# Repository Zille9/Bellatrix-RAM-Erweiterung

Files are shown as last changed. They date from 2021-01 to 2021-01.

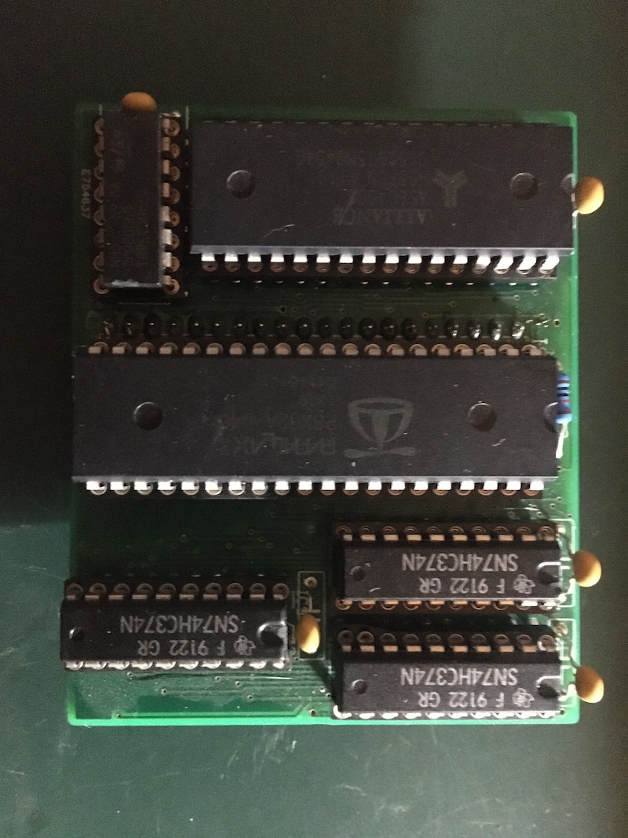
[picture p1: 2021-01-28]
RAM-Erw.JPG

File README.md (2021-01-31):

# Bellatrix-RAM-Erweiterung
Zusätzlicher E-RAM für Bellatrix für die Nutzung von CP/M, TRS80-Emulator, Spectrum-Emulator usw.

Diese Platine wird in den Bellatrixsockel des Hive-Computers gesteckt (Bellatrix selbst kommt auf die Erweiterungsplatine. 
Mit ihr ist es möglich die verschiedenen Emulatoren zu nutzen.
TRS80, ZX-Spectrum, Colour-Genie, Nascom.
Beim Hive-Max ist zusätzlich auch die CP/M-Emulation nutzbar.

HINWEIS: der Videoausgang des HIVE-Boards ist bei Verwendung der Ram-Erweiterung nicht mehr nutzbar. Es ist aber mit einem kleinen Umbau möglich, eine alternative Videofunktion zu realisieren (Pins müssen in den Programmen entsprechend angepasst werden Pin16-19). Siehe auch die Skizze TV.jpg

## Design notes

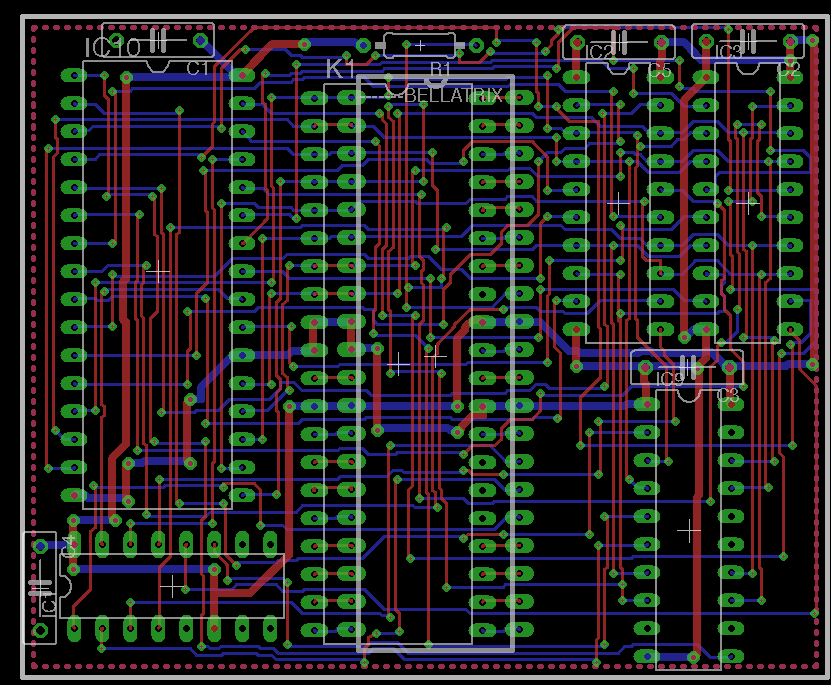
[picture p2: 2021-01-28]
Ram_upgrade_layout.png

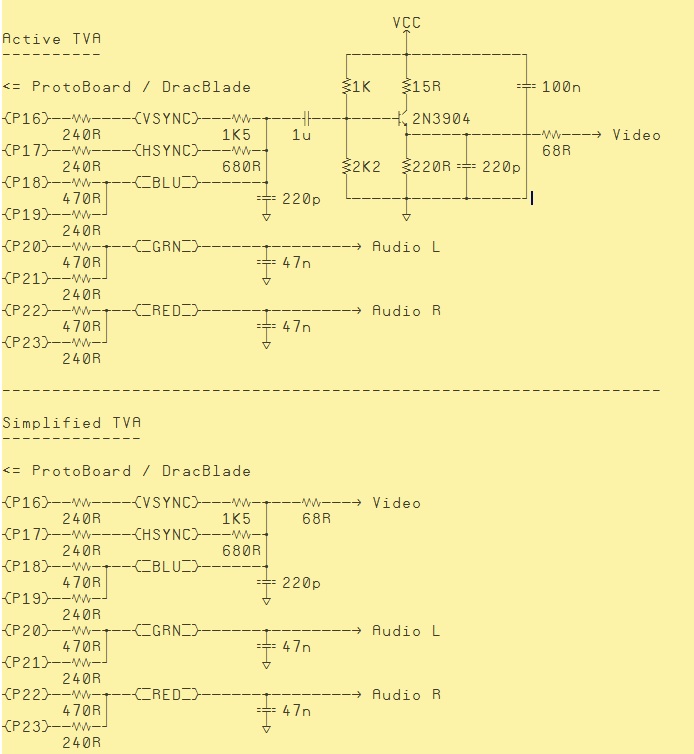
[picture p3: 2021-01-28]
TV.jpg

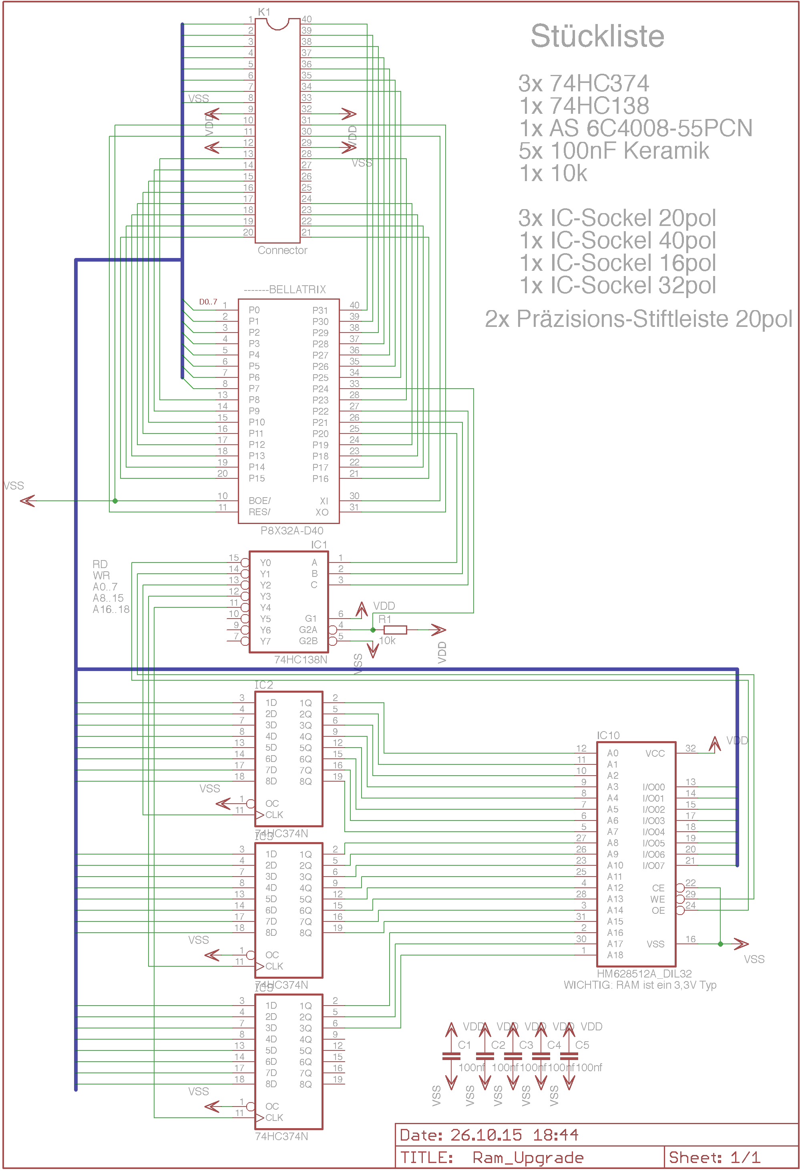
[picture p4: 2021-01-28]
Ram_Upgrade.png

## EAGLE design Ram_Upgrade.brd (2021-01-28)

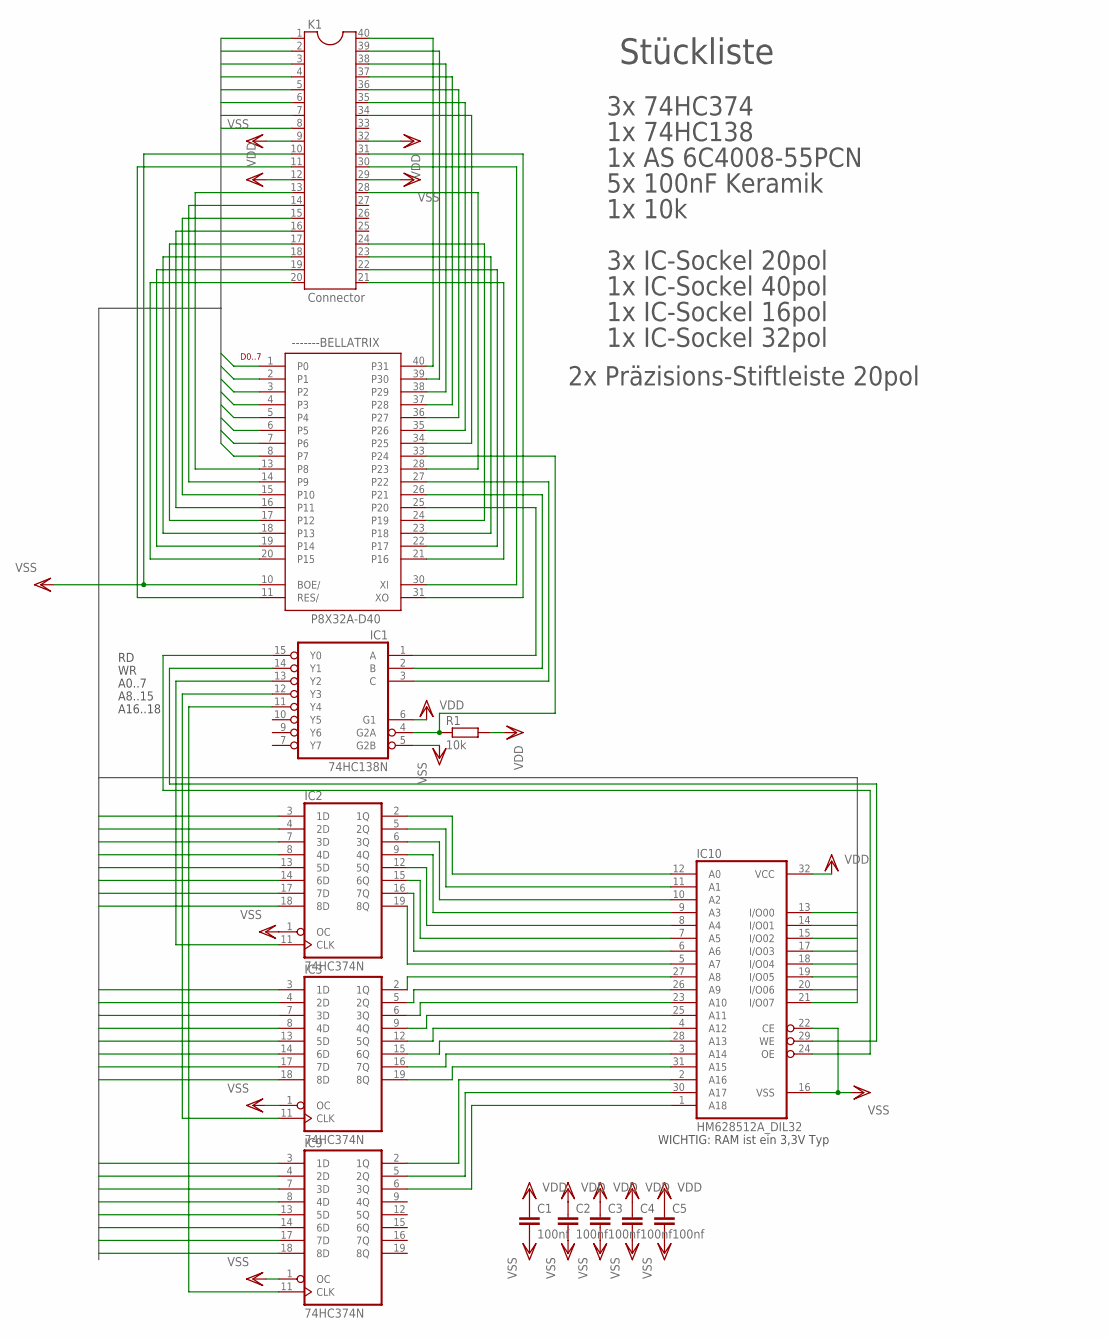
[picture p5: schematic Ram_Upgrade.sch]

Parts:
-------BELLATRIX: P8X32A-D40
C1, C2, C3, C4, C5: 100nf; C075-032X103
IC1: 74HC138N; DIL16
IC2, IC3, IC9: 74HC374N; DIL20
IC10: HM628512A_DIL32; DIL32
K1: Connector; DIL40
R1: 10k; 0207/10

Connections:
BUSCLK: -------BELLATRIX.34 (P25), K1.34
D0: -------BELLATRIX.1 (P0), IC2.3 (1D), IC3.3 (1D), IC9.3 (1D), IC10.13 (I/O00), K1.1
D1: -------BELLATRIX.2 (P1), IC2.4 (2D), IC3.4 (2D), IC9.4 (2D), IC10.14 (I/O01), K1.2
D2: -------BELLATRIX.3 (P2), IC2.7 (3D), IC3.7 (3D), IC9.7 (3D), IC10.15 (I/O02), K1.3
D3: -------BELLATRIX.4 (P3), IC2.8 (4D), IC3.8 (4D), IC9.8 (4D), IC10.17 (I/O03), K1.4
D4: -------BELLATRIX.5 (P4), IC2.13 (5D), IC3.13 (5D), IC9.13 (5D), IC10.18 (I/O04), K1.5
D5: -------BELLATRIX.6 (P5), IC2.14 (6D), IC3.14 (6D), IC9.14 (6D), IC10.19 (I/O05), K1.6
D6: -------BELLATRIX.7 (P6), IC2.17 (7D), IC3.17 (7D), IC9.17 (7D), IC10.20 (I/O06), K1.7
D7: -------BELLATRIX.8 (P7), IC2.18 (8D), IC3.18 (8D), IC9.18 (8D), IC10.21 (I/O07), K1.8
GLOB_RESET: -------BELLATRIX.11 (RES/), K1.11
unnamed: -------BELLATRIX.33 (P24), IC1.4 (G2A), R1.1
unnamed: -------BELLATRIX.28 (P23), K1.28
unnamed: -------BELLATRIX.24 (P19), K1.24
unnamed: IC1.13 (Y2), IC2.11 (CLK)
unnamed: -------BELLATRIX.23 (P18), K1.23
unnamed: IC1.12 (Y3), IC3.11 (CLK)
unnamed: IC1.11 (Y4), IC9.11 (CLK)
unnamed: IC2.2 (1Q), IC10.12 (A0)
unnamed: IC2.5 (2Q), IC10.11 (A1)
unnamed: IC2.6 (3Q), IC10.10 (A2)
unnamed: IC2.9 (4Q), IC10.9 (A3)
unnamed: IC2.12 (5Q), IC10.8 (A4)
unnamed: -------BELLATRIX.22 (P17), K1.22
unnamed: IC2.15 (6Q), IC10.7 (A5)
unnamed: IC2.16 (7Q), IC10.6 (A6)
unnamed: IC2.19 (8Q), IC10.5 (A7)
unnamed: -------BELLATRIX.21 (P16), K1.21
unnamed: IC3.2 (1Q), IC10.27 (A8)
unnamed: IC3.5 (2Q), IC10.26 (A9)
unnamed: IC3.6 (3Q), IC10.23 (A10)
unnamed: -------BELLATRIX.13 (P8), K1.13
unnamed: -------BELLATRIX.31 (XO), K1.31
unnamed: -------BELLATRIX.14 (P9), K1.14
unnamed: -------BELLATRIX.15 (P10), K1.15
unnamed: IC1.14 (Y1), IC10.29 (WE)
unnamed: IC3.9 (4Q), IC10.25 (A11)
unnamed: IC3.12 (5Q), IC10.4 (A12)
unnamed: -------BELLATRIX.37 (P28), K1.37
unnamed: -------BELLATRIX.38 (P29), K1.38
unnamed: -------BELLATRIX.16 (P11), K1.16
unnamed: -------BELLATRIX.17 (P12), K1.17
unnamed: -------BELLATRIX.30 (XI), K1.30
unnamed: -------BELLATRIX.18 (P13), K1.18
unnamed: -------BELLATRIX.19 (P14), K1.19
unnamed: -------BELLATRIX.20 (P15), K1.20
unnamed: IC3.15 (6Q), IC10.28 (A13)
unnamed: IC3.16 (7Q), IC10.3 (A14)
unnamed: IC3.19 (8Q), IC10.31 (A15)
unnamed: IC9.2 (1Q), IC10.2 (A16)
unnamed: IC9.5 (2Q), IC10.30 (A17)
unnamed: IC9.6 (3Q), IC10.1 (A18)
unnamed: -------BELLATRIX.36 (P27), K1.36
unnamed: IC1.15 (Y0), IC10.24 (OE)
unnamed: -------BELLATRIX.25 (P20), IC1.1 (A)
unnamed: -------BELLATRIX.26 (P21), IC1.2 (B)
unnamed: -------BELLATRIX.27 (P22), IC1.3 (C)
RX-H1: -------BELLATRIX.40 (P31), K1.40
TX-H1: -------BELLATRIX.39 (P30), K1.39
VDD: -------BELLATRIX.12 (VDD), -------BELLATRIX.32 (VDD), C1.1, C2.1, C3.1, C4.1, C5.1, IC1.6 (G1), IC1.16 (VDD), IC2.20 (VDD), IC3.20 (VDD), IC9.20 (VDD), IC10.32 (VCC), K1.12, K1.32, R1.2
VSS: -------BELLATRIX.9 (VSS), -------BELLATRIX.10 (BOE/), -------BELLATRIX.29 (VSS), C1.2, C2.2, C3.2, C4.2, C5.2, IC1.5 (G2B), IC1.8 (GND), IC2.1 (OC), IC2.10 (GND), IC3.1 (OC), IC3.10 (GND), IC9.1 (OC), IC9.10 (GND), IC10.16 (VSS), IC10.22 (CE), K1.9, K1.10, K1.29
WR: -------BELLATRIX.35 (P26), K1.35

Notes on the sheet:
D0..7
A0..7
A8..15
A16..18
WICHTIG: RAM ist ein 3,3V Typ
Stückliste
3x 74HC374
1x 74HC138
1x AS 6C4008-55PCN
5x 100nF Keramik
2x Präzisions-Stiftleiste 20pol
3x IC-Sockel 20pol
1x IC-Sockel 40pol
1x IC-Sockel 16pol
1x IC-Sockel 32pol
1x 10k

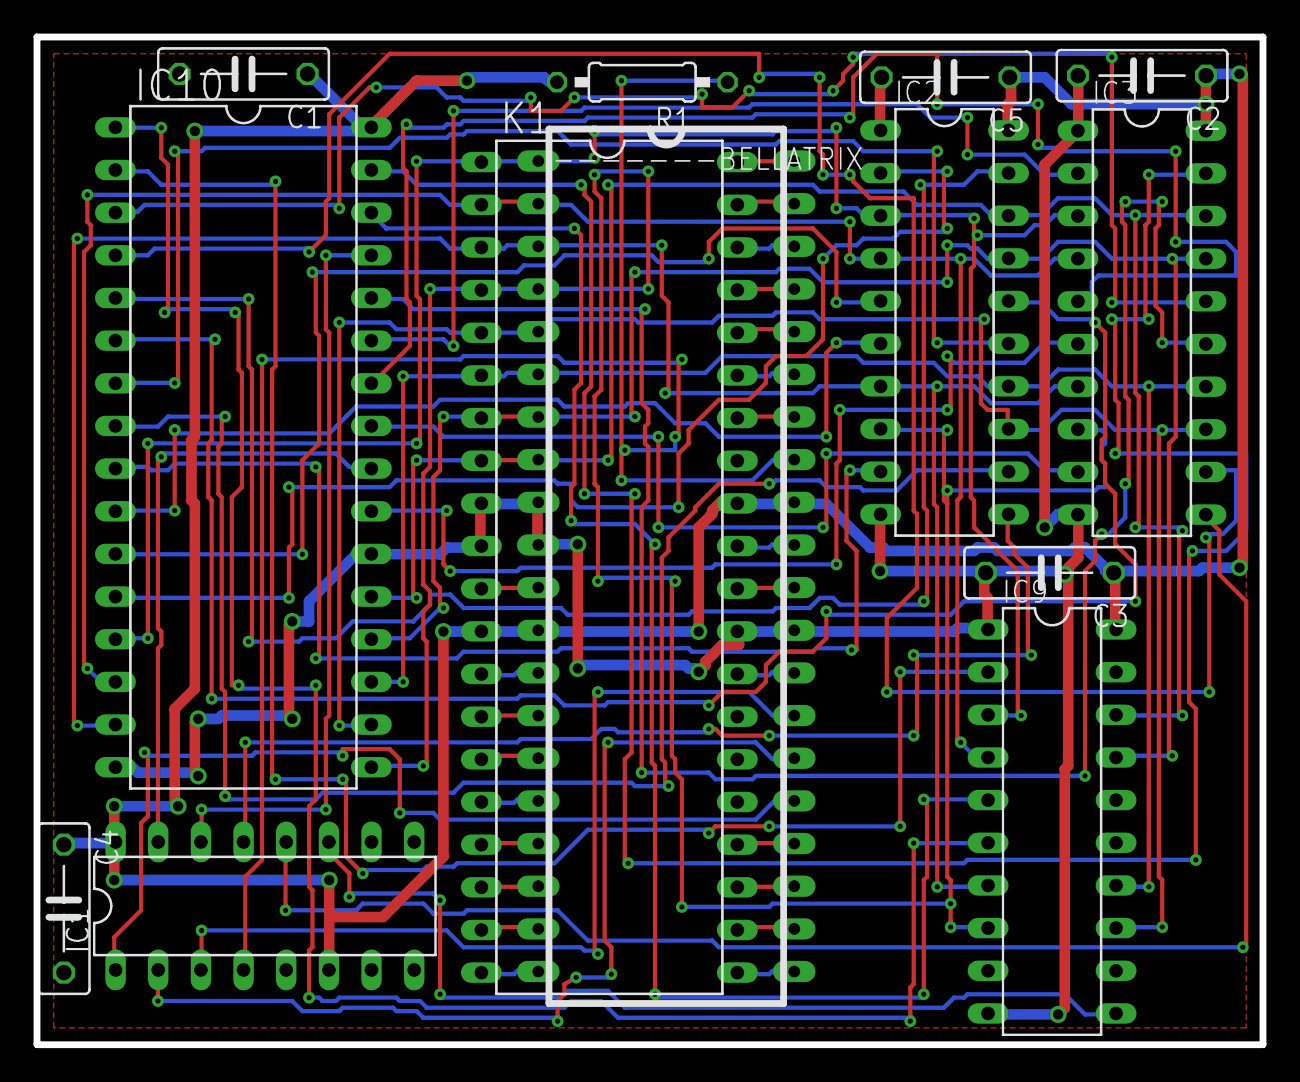
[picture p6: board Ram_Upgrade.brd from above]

Board: 2 copper layers, 73.0 x 60.0 mm, 13 parts (0 on the bottom side), 61 nets.
